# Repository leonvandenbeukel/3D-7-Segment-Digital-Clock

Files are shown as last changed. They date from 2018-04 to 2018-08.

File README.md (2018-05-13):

# 3D-7-Segment-Digital-Clock

This is the source and schema for another homemade digital clock I've made. Here's a link to the [YouTube video](https://youtu.be/QDYH36tWzoY)

Keep in mind that it takes a long time to print all the parts and in daylight it's not very bright.
You can download the Android app from the Play Story here: https://play.google.com/store/apps/details?id=nl.leonvandenbeukel.BTDigitalClockApp

### Print instructions

For better contrast, it's best to print the following parts in black:

* Betweenblock
* BewteenSegments
* DotRing
* Dotbottom
* Middle
* OuterRingSegments

The rest can be printed in white.

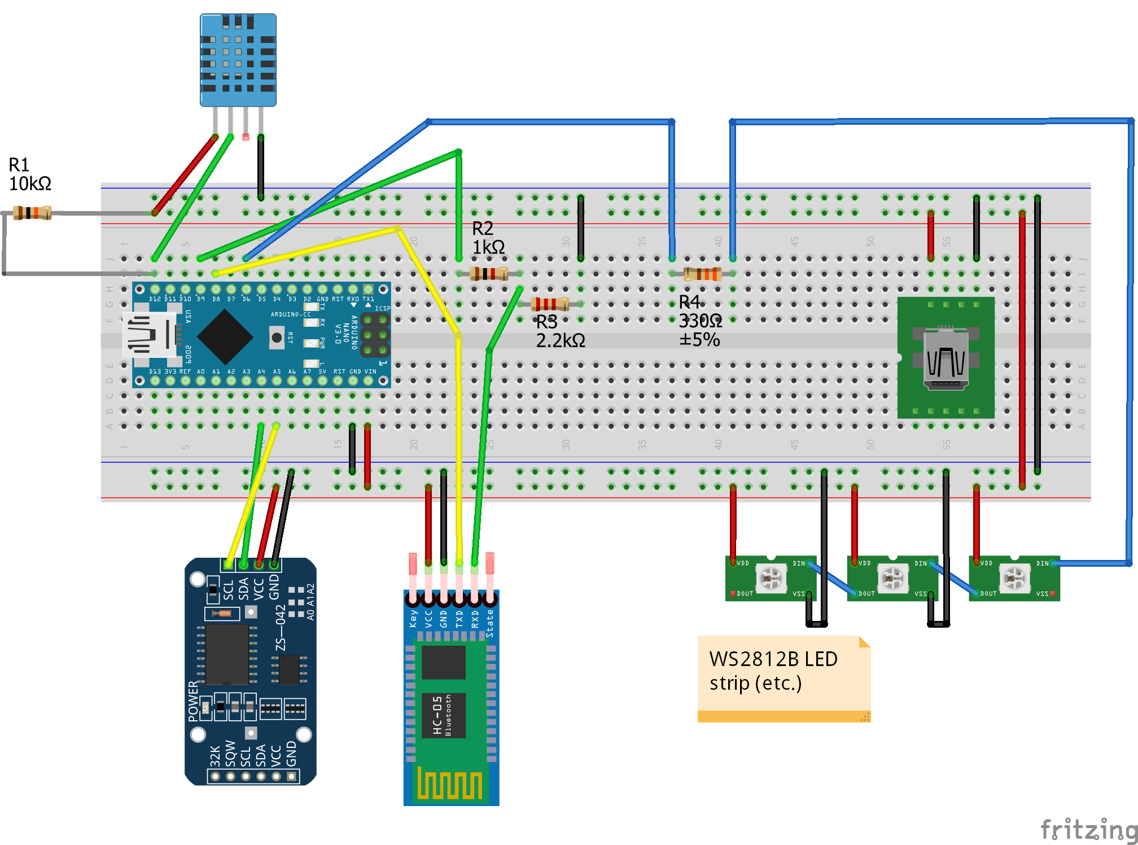
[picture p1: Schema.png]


| Components                              			    |
| -------------                          			      |
| Arduino Nano                           			      |
| LED strip WS2812B 1 meter 30 RGB LED's		 	      |
| Real time clock: DS3231 and battery          		  |
| Bluetooth module: HC-05                 			    |
| Temperature and Humidity Sensor: DHT11 or DHT22  	|
| 5V / 2A  Power Supply								              |
| PCB                                    			      |
| Wires, Glue and a lot of patience :)    			    |

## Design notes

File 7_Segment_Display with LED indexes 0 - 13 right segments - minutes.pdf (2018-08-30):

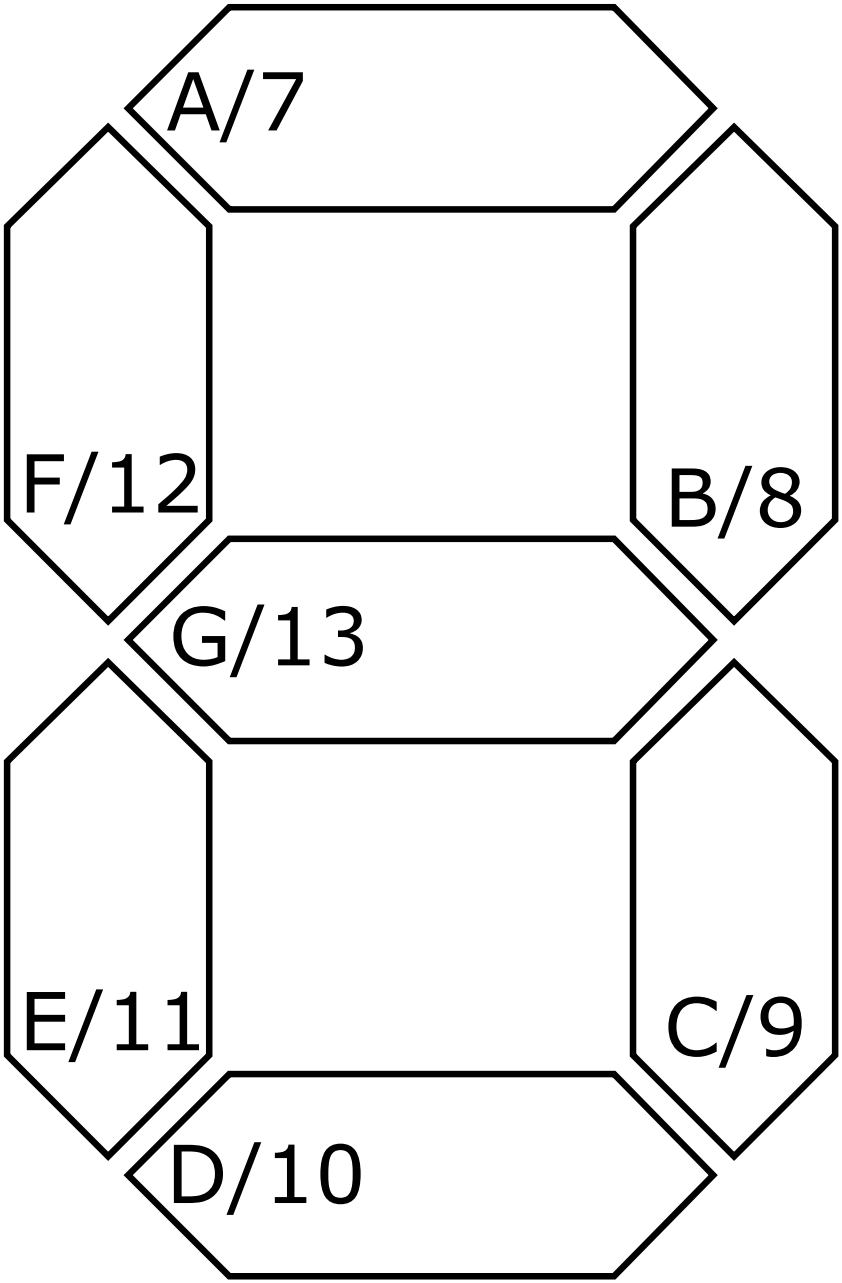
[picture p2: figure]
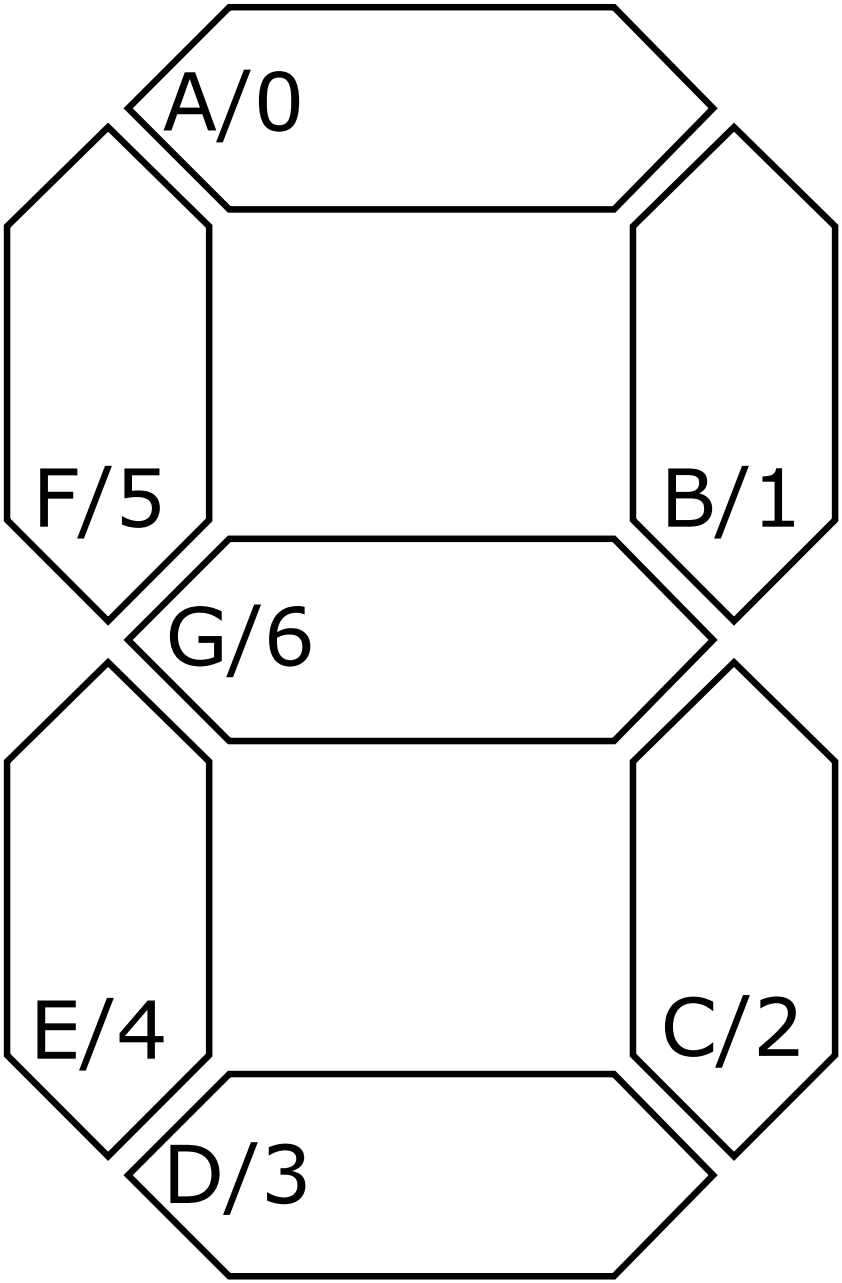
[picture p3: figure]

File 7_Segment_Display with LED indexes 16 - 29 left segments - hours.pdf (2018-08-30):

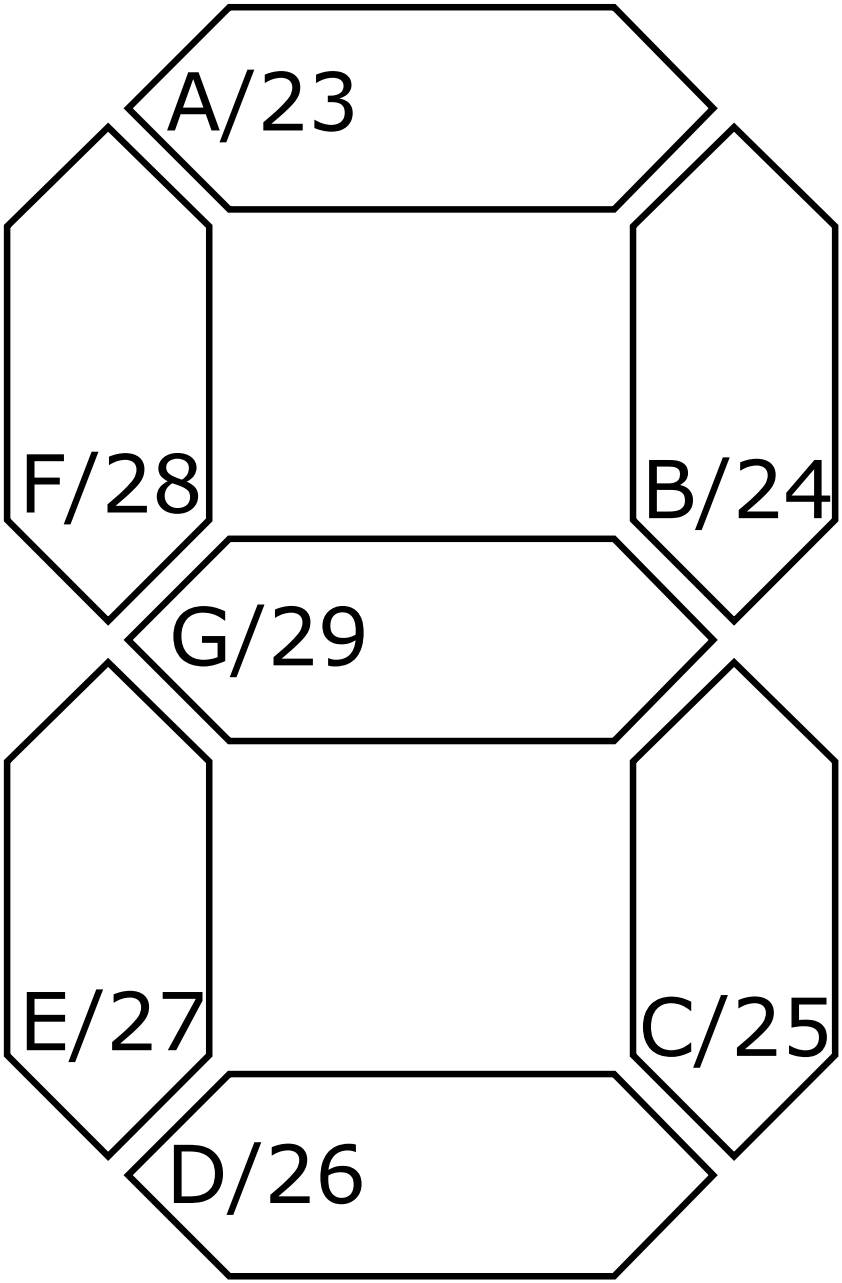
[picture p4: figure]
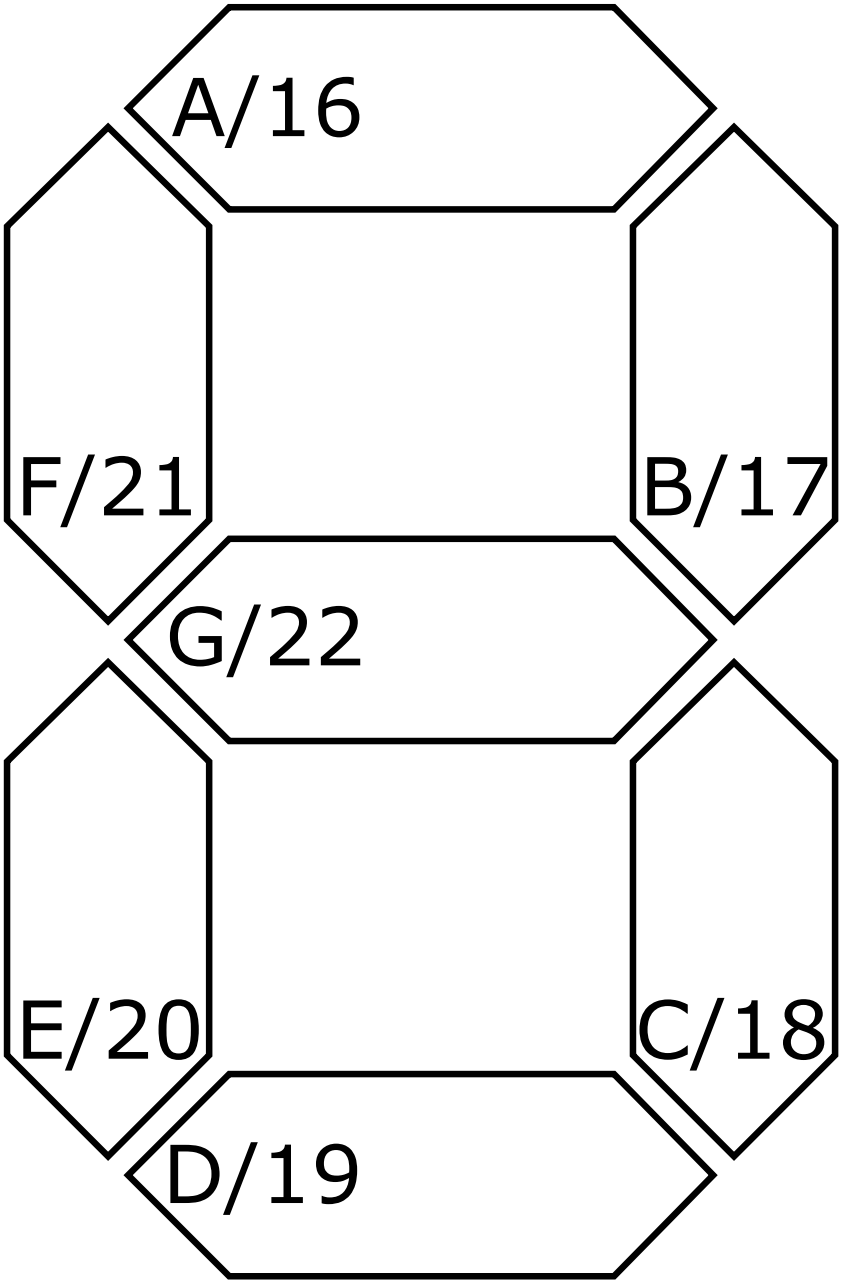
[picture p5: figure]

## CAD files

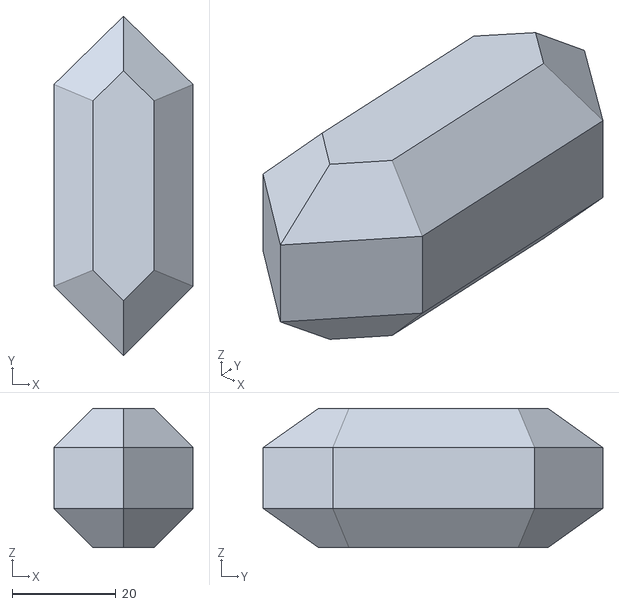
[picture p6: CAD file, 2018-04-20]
STL/Vertical Segment.stl
26.7 x 65.3 x 26.7

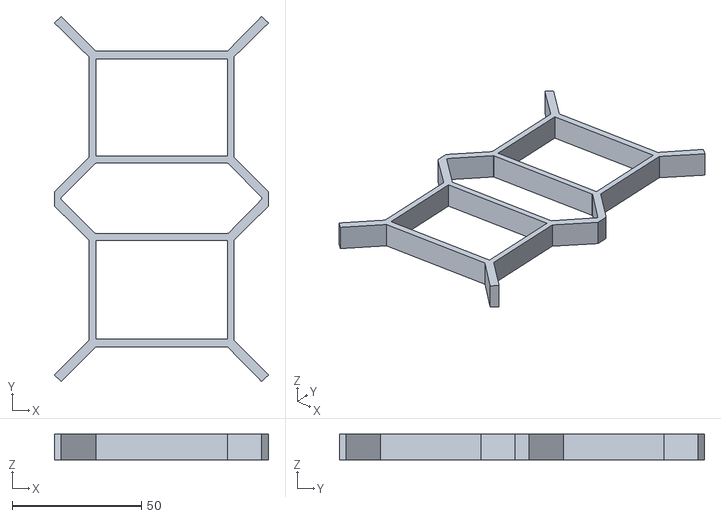
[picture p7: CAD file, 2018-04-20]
STL/BewteenSegments.stl
82.8 x 141.1 x 10.0

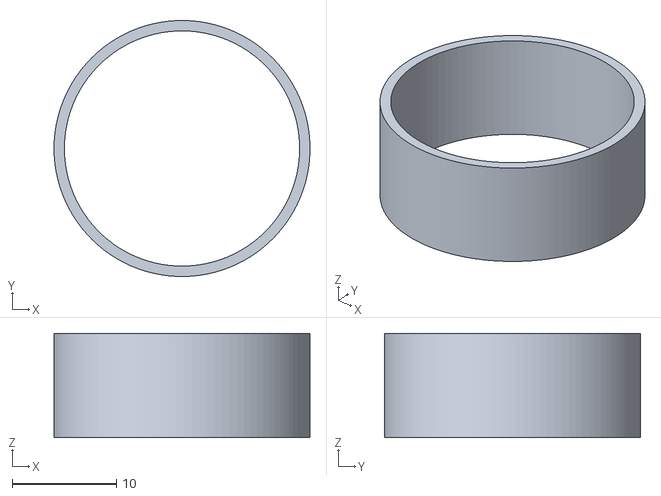
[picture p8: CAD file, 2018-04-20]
STL/DotRing.stl
24.6 x 24.6 x 10.0

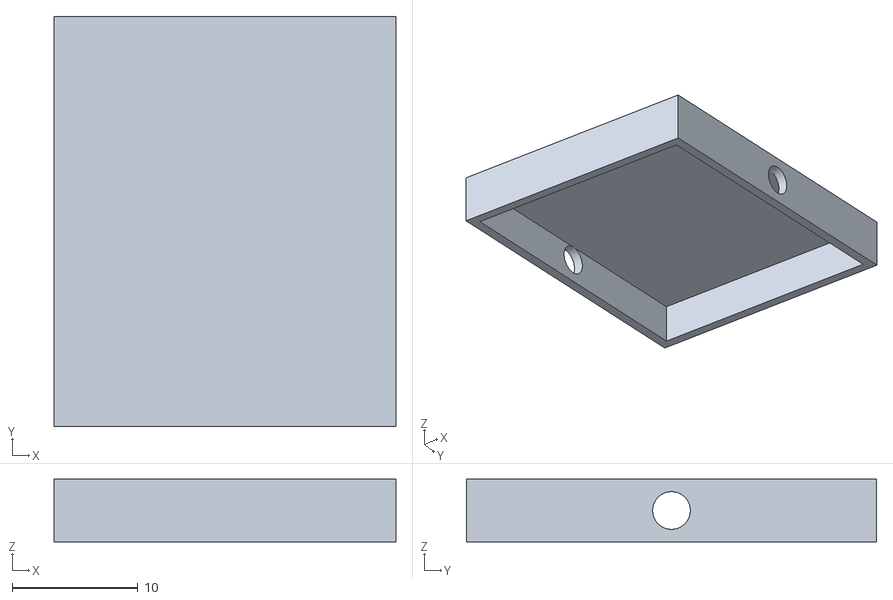
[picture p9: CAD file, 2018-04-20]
STL/Betweenblock.stl
27.2 x 32.6 x 5.00

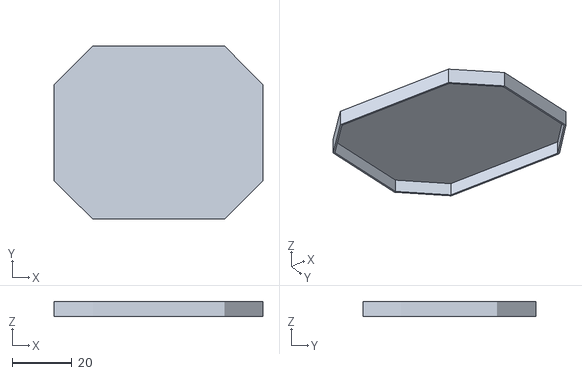
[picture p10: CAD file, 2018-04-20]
STL/Middle.stl
70.3 x 58.2 x 5.00

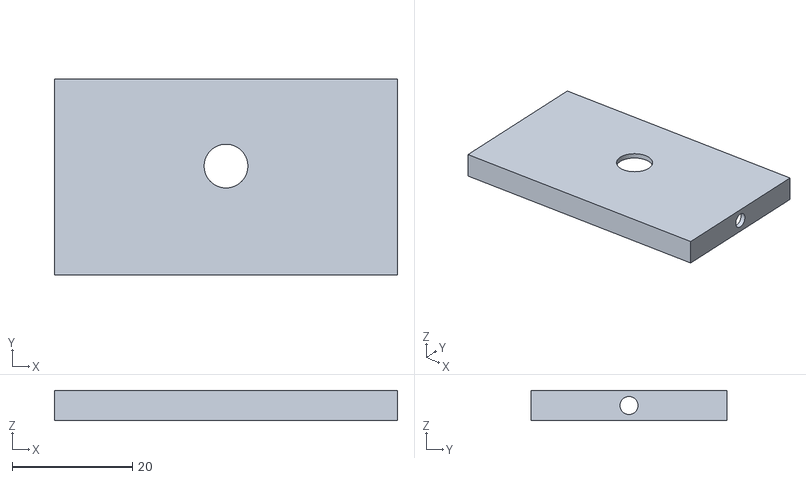
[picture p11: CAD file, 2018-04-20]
STL/Dotbottom.stl
57.0 x 32.6 x 5.00

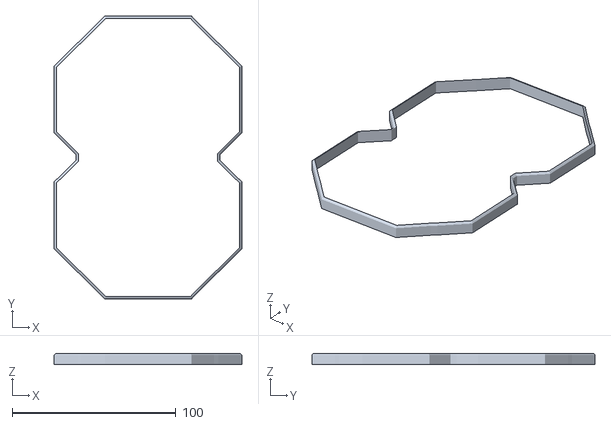
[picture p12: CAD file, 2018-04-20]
STL/OuterRingSegments.stl
114.5 x 172.8 x 7.00

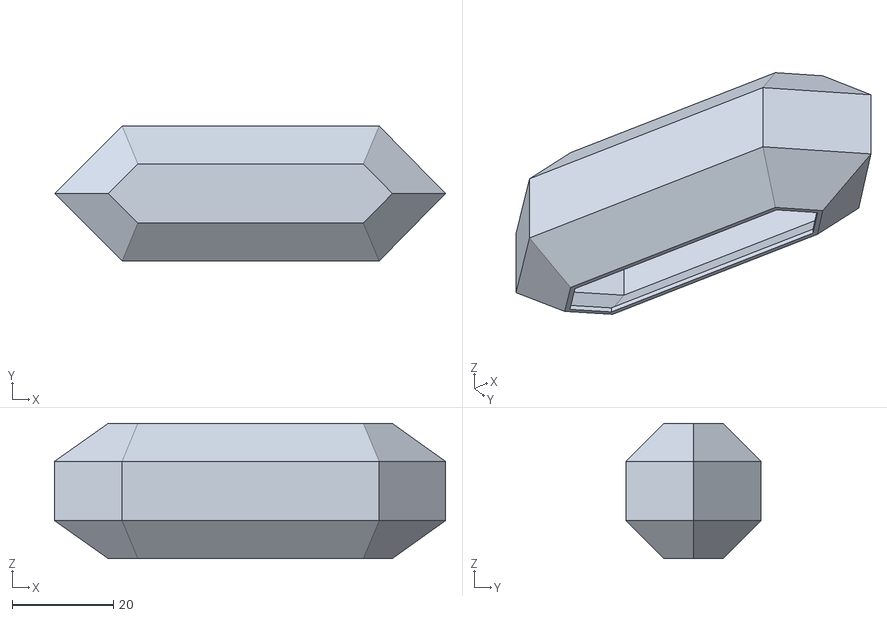
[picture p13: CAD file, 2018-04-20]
STL/Horizontal Segment.stl
77.4 x 26.7 x 26.7

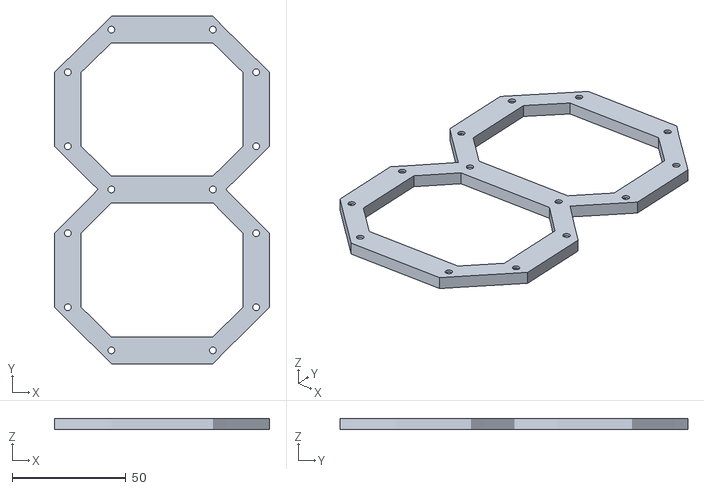
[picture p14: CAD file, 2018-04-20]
STL/Segmentbottom.stl
94.5 x 152.8 x 5.00

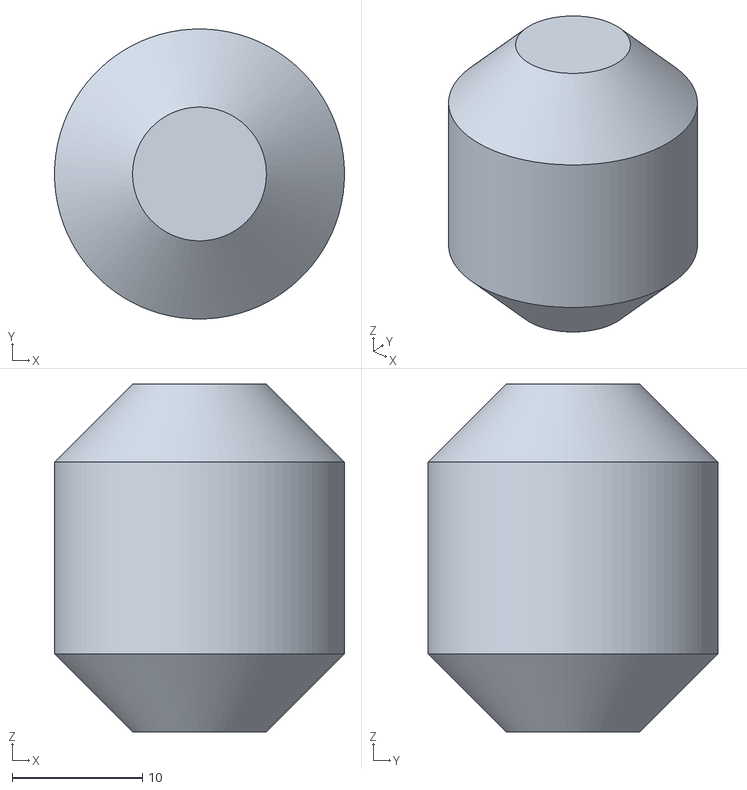
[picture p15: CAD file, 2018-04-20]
STL/Dot.stl
22.3 x 22.3 x 26.7

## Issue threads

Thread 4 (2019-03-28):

Release STL on Thingiverse

fleaz, 2019-03-28:
Hi,

first of all: Thanks for this nice project. Will start to print it myself as soon as I have restocked my PLA ^^

My suggestion would be to publish the STL files on Thingiverse. This way a lot more people would see this cool project and can also share pictures of their prints and start to remix the files or help each other in the comments section.

In my opinion this is a better platform for 3D Objects than GitHub.

Best regards,
Felix

leonvandenbeukel, 2019-05-04:
Hi, sorry for the late response. The STL files are also on thingiverse: https://www.thingiverse.com/thing:2871608

Closed 2019-05-04.

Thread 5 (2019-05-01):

Pease help to sketch

Billyflora, 2019-05-01:
hi, my name is fabio.
I desperately need your help.
unfortunately I have problems with your sketch and I'm not able to fix it ..
I can kindly and politely ask you if you send me a complete and finished sketch to put only on arduino and send it to billyflora@libero.it?
I did not want to bother you but I have everything ready for 6 months but I am still like a stone.
Thanks a lot, I still hope for your help.
Mondellini fabio

leonvandenbeukel, 2019-05-04:
Hi Fabio,

You can find a complete and finished sketch for Arduino here:

https://github.com/leonvandenbeukel/3D-7-Segment-Digital-Clock/blob/master/3D-7-Segment-Digital-Clock.ino

If you have any issues please be more specific with details of what is going wrong.

Regards,
Leon

Billyflora, 2019-05-04:
hi leon.
I thank you very much for your reply.
I managed to start it, but I would like to put two LEDs per segment instead of one ..
unfortunately I don't know how it gets ...
Would you be so kind as to change yours for my watch project?
I saw yours and I immediately fell in love with it, but with a LED you can't see anything.
I thank you so much again ..
I'm sorry for my goat disability!
I'm trying to learn slowly ...

Billyflora, 2019-05-05:
I'm sorry, another thing ...
I can not understand from the video the lap you did do you have led .. I do not understand the pattern of the turn of the LEDs on the printed numbers ..

Closed 2019-05-04.

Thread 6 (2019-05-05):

ciao sono fabio

Billyflora, 2019-05-05:
hi leon.
I thank you very much for your reply.
I managed to start it, but I would like to put two LEDs per segment instead of one ..
unfortunately I don't know how it gets ...
Would you be so kind as to change yours for my watch project?
I saw yours and I immediately fell in love with it, but with a LED you can't see anything.
I thank you so much again ..
I'm sorry for my goat disability!
I'm trying to learn slowly ...

I'm sorry, another thing ...
I can not understand from the video the lap you did do you have led .. I do not understand the pattern of the turn of the LEDs on the printed numbers ..

margaritpoutsi, 2019-11-11:
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

I would change this bit:
```
void displaySegments(int startindex, int number) {

  **byte** numbers[] = {
    0b00111111, // 0
    0b00000110, // 1
    0b01011011, // 2
    0b01001111, // 3
    0b01100110, // 4
    0b01101101, // 5
    0b01111101, // 6
    0b00000111, // 7
    0b01111111, // 8
    0b01101111, // 9
    0b01100011, // º              10
    0b00111001, // C(elcius)      11
    0b01011100, // º lower        12
    0b00000000, // Empty          13
    0b01110001, // F(ahrenheit)   14
  };

  for (int i = 0; i < **7**; i++) {
    LEDs[i + startindex] = ((numbers[number] & 1 << i) == 1 << i) ? (colorMODE == 0 ? colorCRGB : colorCHSV) : colorOFF;
  }
}
```

to this:
```
void displaySegments(int startindex, int number) {

  **int** numbers[] = {
    0b000111111111111, // 0
    0b000000000111100, // 1
    0b011001111001111, // 2
    0b011000011111111, // 3
    0b011110000111100, // 4
    0b011110011110011, // 5
    0b011111111110011, // 6
    0b000000000111111, // 7
    0b011111111111111, // 8
    0b011110011111111, // 9
    0b011110000001111, // º              10
    0b000111111000011, // C(elcius)      11
    0b011001111110000, // º lower        12
    0b000000000000000, // Empty          13
    0b011111100000011, // F(ahrenheit)   14
  };

  for (int i = 0; i < **14**; i++) {
    LEDs[i + startindex] = ((numbers[number] & 1 << i) == 1 << i) ? (colorMODE == 0 ? colorCRGB : colorCHSV) : colorOFF;
  }
}
```
and this:
  ```
  displaySegments(**0**, mr);
  displaySegments(**7**, ml);
  displaySegments(**16**, hr);
  displaySegments(**23**, hl);
```

to:
```
  displaySegments(**0**, mr);
  displaySegments(**14**, ml);
  displaySegments(**30**, hr);
  displaySegments(**44**, hl);
etc.
```

Dante6214, 2019-11-22:
Hi, the easiest way to make 2 LEDs per segment is to make a diagram so that there is a parallel connection of 2 LEDs as in the picture. And absolutely no need to change the sketch.
The picture is available at  link:
https://yadi.sk/i/FBnUcPGQ3qxf7w

pakobrien, 2021-04-17:
I do this but my dots don´t blink,the segment number 8 (leds 15 and 16)are always on and blinking,any solution?

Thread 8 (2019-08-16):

problem with LED

icepol001, 2019-08-16:
I made your clock but I have a problem with LEDs.
places that should not shine are glowing white. can you help me ? thank you

Milius605, 2019-08-17:
I have same problem. Pls help :-D

leonvandenbeukel, 2019-08-18:
Please check the .ino file on line 59:

CRGB colorOFF  = CRGB(20,20,20);      // Color of the segments that are 'disabled'. You can also set it to CRGB::Black

Change "CRGB(20,20,20)" to CRGB::Black if you don't want a glowing white.

Milius605, 2019-08-18:
It works! Thank you very much for your help and quick response

Closed 2019-08-19.

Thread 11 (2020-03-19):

Bluetooth

bilacom, 2020-03-19:
Hai Leon, I'm very interesting of your project and tried to make one, but I have problem with bluetooth connection.after I installed the aplication from playstore and trial it couldnt connect the bluetooth, aplication suddenly stop and close right after i click the BT device. FYI i use HC-06 instead of HC-05.

kikidu971-cpu, 2024-09-11:
Hi Leon,
I'm also interested in your clock. for the blutooth to work, I suppose i need the (digital clock app) installed on a smartphone. I haven't found the apk to install it. where can I find it? thanks.
chris

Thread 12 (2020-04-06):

HELP !! electric scheme

COIScois, 2020-04-06:
Thank you for this wonderful project.
As a CNC miller, the electrical part is a nice bump to take.
I follow the two schemes for the left and right digit groups.
I still follow the PCB board.
But do you also have a schedule where the 2 points are connected?

That is a mystery to me. That is certainly my ignorance!

thanks again for this great project.

dank je wel, François H

Closed 2020-04-06.

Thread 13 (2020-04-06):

Je hulp gevraagd !?

COIScois, 2020-04-06:
Thank you for this wonderful project.
As a CNC miller, the electrical part is a nice bump to take.
I follow the two schemes for the left and right digit groups.
I still follow the PCB board.
But do you also have a schedule where the 2 points are connected?

That is a mystery to me. That is certainly my ignorance!

thanks again for this great project.

dank je wel, François H

leonvandenbeukel, 2020-06-26:
They are connected in between the segments, just follow the LEDs from right to left.

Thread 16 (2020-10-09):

Resistor Conflict

DeimonGaming, 2020-10-09:
Im in the middle of creating this project. But ive been stuck on the R1, the resistor is placed at the same place as the humidity sensor can you please enlighten me

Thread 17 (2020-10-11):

Temp and Humidity not working

DeimonGaming, 2020-10-11:
I already finish this project, but im not submitting it yet the other functions like time, colors, scoreboard and timer are working but the temp and humidity is not ive already tried replacing wires and it still didnt work please help ASAP

madeinholland, 2021-05-08:
I have the same issue , Humidity and temp is not working

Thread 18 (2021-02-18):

'displayClock' was not declared in this scope

djgorandj, 2021-02-18:
Arduino say this:
'displayClock' was not declared in this scope
how to resolve this problem?

djgorandj, 2021-02-18:
Upload working, dont use beta 1.9 ardiono

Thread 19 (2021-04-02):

Lamps won't turn on

madeinholland, 2021-04-02:
I have gone to upload the firmware with the liberals tho the nano.
But when I am connected to de Bluetooth HC-05 and in the app, the lamp doesn't work.

my wiring is good it has voltage over eas lamp (+5v).  The only thing is it won't light up any of the lamps I think it lays in the android app. because I didn't make any changes in the liberals and your document.

the Din and ground do not have voltage over them. Besides that, the lamps can be turned on when I put voltage over them.
P.S I did not yet power it from the adaptor but with my pc.

Leon, can you help me tho finish your product?

Alex-Ender35, 2023-06-17:
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

Hello. Have you been able to solve the problem with the lamps not working? If so, how?

Closed 2021-05-08.

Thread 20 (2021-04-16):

problems with dots

pakobrien, 2021-04-16:
Hi Leon, first thank you very much for the project, I really liked it and I decided to do it.
The problem I have is that I have manufactured your watch but with two LEDs, I have read the posts and I have modified the .ino but now the points do not work and I have the A7 segment blinking as if they were the points, in the points I have only put a led in each one, I have a total of 58 leds, what should I change to fix this? The humidity temperature does not work either, thanks in advance

pakobrien, 2021-04-17:
resolved,I need to change this:

void displayDots(int dotMode) {
  // dotMode: 0=Both on, 1=Both Off, 2=Bottom On, 3=Blink
  switch (dotMode) {
    case 0:
      LEDs[28] = colorMODE == 0 ? colorCRGB : colorCHSV;
      LEDs[29] = colorMODE == 0 ? colorCRGB : colorCHSV;
      break;
    case 1:
      LEDs[28] = colorOFF;
      LEDs[29] = colorOFF;
      break;
    case 2:
      LEDs[28] = colorOFF;
      LEDs[29] = colorMODE == 0 ? colorCRGB : colorCHSV;
      break;
    case 3:
      LEDs[28] = (LEDs[28] == colorOFF) ? (colorMODE == 0 ? colorCRGB : colorCHSV) : colorOFF;
      LEDs[29] = (LEDs[29] == colorOFF) ? (colorMODE == 0 ? colorCRGB : colorCHSV) : colorOFF;
      FastLED.show();

Closed 2021-04-17.

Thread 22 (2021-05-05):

Problems compiling

m0nde, 2021-05-05:
I am no expert in Arduino and trying to build this clock for my son. I have built the hardware and he has printed all the clock pieces. When I compile the code for the nano I get this error.  Can someone please help me get past this issue please?
Arduino: 1.8.13 (Windows 10), Board: "Arduino Nano, ATmega328P"

In file included from C:\Users\nigel\Documents\Arduino\libraries\src/bitswap.h:4:0,

                 from C:\Users\nigel\Documents\Arduino\3D-7-Segment-Digital-Clock-master\3D-7-Segment-Digital-Clock-master\3D-7-Segment-Digital-Clock\3D-7-Segment-Digital-Clock.ino:1:

C:\Users\nigel\Documents\Arduino\libraries\src/FastLED.h:14:21: note: #pragma message: FastLED version 3.004.000

 #    pragma message "FastLED version 3.004.000"

                     ^~~~~~~~~~~~~~~~~~~~~~~~~~~

C:\Users\nigel\AppData\Local\Temp\ccKsavlE.ltrans0.ltrans.o: In function `displayClock':

C:\Users\nigel\Documents\Arduino\3D-7-Segment-Digital-Clock-master\3D-7-Segment-Digital-Clock-master\3D-7-Segment-Digital-Clock/3D-7-Segment-Digital-Clock.ino:267: undefined reference to `RTC_DS3231::now()'

C:\Users\nigel\AppData\Local\Temp\ccKsavlE.ltrans0.ltrans.o: In function `processCommand':

C:\Users\nigel\Documents\Arduino\3D-7-Segment-Digital-Clock-master\3D-7-Segment-Digital-Clock-master\3D-7-Segment-Digital-Clock/3D-7-Segment-Digital-Clock.ino:240: undefined reference to `DateTime::DateTime(unsigned int, unsigned char, unsigned char, unsigned char, unsigned char, unsigned char)'

C:\Users\nigel\Documents\Arduino\3D-7-Segment-Digital-Clock-master\3D-7-Segment-Digital-Clock-master\3D-7-Segment-Digital-Clock/3D-7-Segment-Digital-Clock.ino:240: undefined reference to `RTC_DS3231::adjust(DateTime const&)'

C:\Users\nigel\AppData\Local\Temp\ccKsavlE.ltrans0.ltrans.o: In function `global constructors keyed to 65535_0_3D_7_Segment_Digital_Clock.ino.cpp.o.4410':

<artificial>:(.text.startup+0x1bc): undefined reference to `Timer::Timer()'

<artificial>:(.text.startup+0x1c4): undefined reference to `Timer::Timer()'

<artificial>:(.text.startup+0x1cc): undefined reference to `Timer::Timer()'

C:\Users\nigel\AppData\Local\Temp\ccKsavlE.ltrans0.ltrans.o: In function `setup':

C:\Users\nigel\Documents\Arduino\3D-7-Segment-Digital-Clock-master\3D-7-Segment-Digital-Clock-master\3D-7-Segment-Digital-Clock/3D-7-Segment-Digital-Clock.ino:118: undefined reference to `RTC_DS3231::begin()'

C:\Users\nigel\Documents\Arduino\3D-7-Segment-Digital-Clock-master\3D-7-Segment-Digital-Clock-master\3D-7-Segment-Digital-Clock/3D-7-Segment-Digital-Clock.ino:123: undefined reference to `RTC_DS3231::lostPower()'

C:\Users\nigel\Documents\Arduino\3D-7-Segment-Digital-Clock-master\3D-7-Segment-Digital-Clock-master\3D-7-Segment-Digital-Clock/3D-7-Segment-Digital-Clock.ino:126: undefined reference to `DateTime::DateTime(__FlashStringHelper const*, __FlashStringHelper const*)'

C:\Users\nigel\Documents\Arduino\3D-7-Segment-Digital-Clock-master\3D-7-Segment-Digital-Clock-master\3D-7-Segment-Digital-Clock/3D-7-Segment-Digital-Clock.ino:126: undefined reference to `RTC_DS3231::adjust(DateTime const&)'

C:\Users\nigel\Documents\Arduino\3D-7-Segment-Digital-Clock-master\3D-7-Segment-Digital-Clock-master\3D-7-Segment-Digital-Clock/3D-7-Segment-Digital-Clock.ino:129: undefined reference to `Timer::every(unsigned long, void (*)())'

C:\Users\nigel\Documents\Arduino\3D-7-Segment-Digital-Clock-master\3D-7-Segment-Digital-Clock-master\3D-7-Segment-Digital-Clock/3D-7-Segment-Digital-Clock.ino:130: undefined reference to `Timer::every(unsigned long, void (*)())'

C:\Users\nigel\Documents\Arduino\3D-7-Segment-Digital-Clock-master\3D-7-Segment-Digital-Clock-master\3D-7-Segment-Digital-Clock/3D-7-Segment-Digital-Clock.ino:131: undefined reference to `Timer::every(unsigned long, void (*)())'

C:\Users\nigel\AppData\Local\Temp\ccKsavlE.ltrans0.ltrans.o: In function `loop':

C:\Users\nigel\Documents\Arduino\3D-7-Segment-Digital-Clock-master\3D-7-Segment-Digital-Clock-master\3D-7-Segment-Digital-Clock/3D-7-Segment-Digital-Clock.ino:137: undefined reference to `Timer::update()'

C:\Users\nigel\Documents\Arduino\3D-7-Segment-Digital-Clock-master\3D-7-Segment-Digital-Clock-master\3D-7-Segment-Digital-Clock/3D-7-Segment-Digital-Clock.ino:138: undefined reference to `Timer::update()'

C:\Users\nigel\Documents\Arduino\3D-7-Segment-Digital-Clock-master\3D-7-Segment-Digital-Clock-master\3D-7-Segment-Digital-Clock/3D-7-Segment-Digital-Clock.ino:139: undefined reference to `Timer::update()'

collect2.exe: error: ld returned 1 exit status

exit status 1

Error compiling for board Arduino Nano.

This report would have more information with
"Show verbose output during compilation"
option enabled in File -> Preferences.

Alex-Ender35, 2023-06-15:
Hello, m0nde, you managed to solve your problem with the compilation errors. If so, how?

Alex-Ender35, 2023-06-15:
Какие библиотеки вы использовали? Или может быть внесли изменения в коде прошивки?

m0nde, 2023-06-15:
Sorry no luck here

kind regards

Nigel

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

Alex-Ender35, 2023-06-15:
> Извините, здесь не повезло, с уважением, Найджел.
> […](#)
> Чт, 15 Июн 2023, 02:36 Alex-Ender35, ***@***.***> написал: Здравствуйте, m0nde, вам удалось решить проблему с ошибками компиляции. Если да, то как? — Ответьте на это письмо напрямую, просмотрите его на GitHub < [# 22 (комментарий)](https://github.com/leonvandenbeukel/3D-7-Segment-Digital-Clock/issues/22#issuecomment-1592201153) > или отмените подписку < https://github.com/notifications/unsubscribe-auth/ACJHOW2OUBRURH4WYW3SLXDXLJRJDANCNFSM44FM7I6A > . Вы получили это сообщение, потому что являетесь автором темы. Идентификатор сообщения: ***@***.*** com>

Genasaf, 2024-05-09:
Все работает скетч грузится

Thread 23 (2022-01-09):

error

JBHTv, 2022-01-09:
Sketch uses 18084 bytes (58%) of program storage space. Maximum is 30720 bytes.
Global variables use 1491 bytes (72%) of dynamic memory, leaving 557 bytes for local variables. Maximum is 2048 bytes.
avrdude: stk500_recv(): programmer is not responding
avrdude: stk500_getsync() attempt 1 of 10: not in sync: resp=0x04
avrdude: stk500_recv(): programmer is not responding
avrdude: stk500_getsync() attempt 2 of 10: not in sync: resp=0x04
avrdude: stk500_recv(): programmer is not responding
avrdude: stk500_getsync() attempt 3 of 10: not in sync: resp=0x04
avrdude: stk500_recv(): programmer is not responding
avrdude: stk500_getsync() attempt 4 of 10: not in sync: resp=0x04
avrdude: stk500_recv(): programmer is not responding
avrdude: stk500_getsync() attempt 5 of 10: not in sync: resp=0x04
avrdude: stk500_recv(): programmer is not responding
avrdude: stk500_getsync() attempt 6 of 10: not in sync: resp=0x04
avrdude: stk500_recv(): programmer is not responding
avrdude: stk500_getsync() attempt 7 of 10: not in sync: resp=0x04
avrdude: stk500_recv(): programmer is not responding
avrdude: stk500_getsync() attempt 8 of 10: not in sync: resp=0x04
avrdude: stk500_recv(): programmer is not responding
avrdude: stk500_getsync() attempt 9 of 10: not in sync: resp=0x04
avrdude: stk500_recv(): programmer is not responding
avrdude: stk500_getsync() attempt 10 of 10: not in sync: resp=0x04
Problem uploading to board.  See https://support.arduino.cc/hc/en-us/sections/360003198300 for suggestions.

JBHTv, 2022-01-09:
only change processor to ATmega328p (Old Bootloader)

Closed 2022-01-09.

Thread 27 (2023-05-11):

Arduino software

lorcott, 2023-05-11:
I'm using an ESP32 and I cannot find the code to run the clock. Any help greatly appreciated.

slevine@lorcott.com
s

aeonSolutions, 2023-06-17:
I can do that for you. Send me a message to WhatsApp +32 471 632 520

Genasaf, 2024-04-14:
help with the application it is not on google play

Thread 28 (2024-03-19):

Google play missing app

tamgor, 2024-03-19:
I changed my phone, unfortunately there is no more app on google play.

Im asking for help

ZioRaff, 2024-04-06:
I have the same problem but can't I get the app code?

Genasaf, 2024-04-14:
Поделитесь файлом загрузки приложения приложения

pjaspinski, 2024-07-03:
I made a Python script that can connect to the clock and set current time. You can find it here: https://github.com/pjaspinski/digital-clock-toolkit

Another way of communicating with the clock is to get an app that can send serial Bluetooth 2 messages. I successfully used this app: https://play.google.com/store/apps/details?id=de.kai_morich.serial_bluetooth_terminal
If you look into `processMessage` function in clock's code, you can deduct format of messages. For example, message used to set time has following format: `|RTC,2024,07,03,19,55,06`.

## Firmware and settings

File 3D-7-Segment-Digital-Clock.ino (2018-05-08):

/*
 * MIT License
 * 
 * Copyright (c) 2018 Leon van den Beukel
 * 
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
 * Source: 
 * https://github.com/leonvandenbeukel/3D-7-Segment-Digital-Clock
 * 
 * External libraries you need:
 * Adafruit Sensor Library:   https://github.com/adafruit/Adafruit_Sensor
 * Adafruit RTCLib:           https://github.com/adafruit/RTClib
 * FastLED:                   https://github.com/FastLED/FastLED
 * Timer Library:             https://github.com/JChristensen/Timer
 */

#include <DHT.h>
#include <DHT_U.h>
#include <FastLED.h>
#include <Wire.h>
#include "RTClib.h"
#include <SoftwareSerial.h>
#include "Timer.h"

#define DHTPIN 12
#define DHTTYPE DHT11
DHT dht(DHTPIN, DHTTYPE);

#define NUM_LEDS 30     
#define DATA_PIN 6
CRGB LEDs[NUM_LEDS];

SoftwareSerial BTserial(8, 9);
RTC_DS3231 rtc;
Timer t1;
Timer t2;
Timer t3;

String btBuffer;
CRGB colorCRGB = CRGB::Red;           // Change this if you want another default color, for example CRGB::Blue
CHSV colorCHSV = CHSV(95, 255, 255);  // Green
CRGB colorOFF  = CRGB(20,20,20);      // Color of the segments that are 'disabled'. You can also set it to CRGB::Black
volatile int colorMODE = 1;           // 0=CRGB, 1=CHSV, 2=Constant Color Changing pattern
volatile int mode = 0;                // 0=Clock, 1=Temperature, 2=Humidity, 3=Scoreboard, 4=Time counter
volatile int scoreLeft = 0;
volatile int scoreRight = 0;
volatile long timerValue = 0;
volatile int timerRunning = 0;

#define blinkDots   0                 // Set this to 1 if you want the dots to blink in clock mode, set it to value 0 to disable
#define hourFormat  24                // Set this to 12 or to 24 hour format
#define temperatureMode 'C'           // Set this to 'C' for Celcius or 'F' for Fahrenheit

void setup () {

  // Initialize LED strip
  FastLED.delay(3000);

  // Check if you're LED strip is a RGB or GRB version (third parameter)
  FastLED.addLeds<WS2812B, DATA_PIN, GRB>(LEDs, NUM_LEDS);

  Serial.begin(9600);
  while (!Serial) { /* Wait until serial is ready */ }

  BTserial.begin(9600);
  Serial.println("BTserial started at 9600");

  dht.begin();

  if (!rtc.begin()) {
    Serial.println("Couldn't find RTC");
    while (1);
  }

  if (rtc.lostPower()) {
    Serial.println("RTC lost power, lets set the time!");
    // following line sets the RTC to the date & time this sketch was compiled
    rtc.adjust(DateTime(F(__DATE__), F(__TIME__)));
  }
    
  t1.every(1000 * 29, refreshDisplay); 
  t2.every(1000, refreshTimer);
  t3.every(50, updateHue);
  refreshDisplay();
}

void loop () {
  
  t1.update(); 
  t2.update();
  t3.update();

  if (BTserial.available())
  {
    char received = BTserial.read();
    btBuffer += received; 

    if (received == '|')
    {
        processCommand();
        btBuffer = "";
    }
  }
}

void updateHue() {
  if (colorMODE != 2)
    return;
    
  colorCHSV.sat = 255;
  colorCHSV.val = 255;
  if (colorCHSV.hue >= 255){
    colorCHSV.hue = 0;
  } else {
    colorCHSV.hue++;
  }
  refreshDisplay();
}

void refreshDisplay() {
  switch (mode) {
    case 0:
      displayClock();
      break;
    case 1:
      displayTemperature();
      break;
    case 2:
      displayHumidity();
      break;
    case 3:
      displayScoreboard();
      break;      
    case 4:
      // Time counter has it's own timer
      break;
    default:   
      break; 
  }
}

void refreshTimer() {

  if (mode == 0 && blinkDots == 1) {    
    displayDots(3);
  } else if (mode == 4 && timerRunning == 1 && timerValue < 6000) {
    timerValue++;

    int m1 = (timerValue / 60) / 10 ;
    int m2 = (timerValue / 60) % 10 ;
    int s1 = (timerValue % 60) / 10;
    int s2 = (timerValue % 60) % 10;
  
    displaySegments(0, s2); 
    displaySegments(7, s1);
    displaySegments(16, m2);    
    displaySegments(23, m1);  
    displayDots(0);  
    FastLED.show();
  }
}

void processCommand(){

  if (btBuffer.startsWith("RGBD")) {
    long R = getValue(btBuffer, ',', 1).toInt();
    long G = getValue(btBuffer, ',', 2).toInt();
    long B = getValue(btBuffer, ',', 3).toInt();
    long D = getValue(btBuffer, ',', 4).toInt();
    colorCRGB.red = R;
    colorCRGB.green = G;
    colorCRGB.blue = B;
    colorMODE = 0;
    if (D > 0) FastLED.setBrightness(D); 
  } else if (btBuffer.startsWith("HSVD")) {
    long H = getValue(btBuffer, ',', 1).toInt();
    long S = getValue(btBuffer, ',', 2).toInt();
    long V = getValue(btBuffer, ',', 3).toInt();
    long D = getValue(btBuffer, ',', 4).toInt();
    colorCHSV.hue = H;
    colorCHSV.sat = S;
    colorCHSV.val = V;
    colorMODE = 1;
    if (D > 0) FastLED.setBrightness(D);
  } else if (btBuffer.startsWith("RTC")) {
    long y = getValue(btBuffer, ',', 1).toInt();
    long m = getValue(btBuffer, ',', 2).toInt();
    long d = getValue(btBuffer, ',', 3).toInt();
    long h = getValue(btBuffer, ',', 4).toInt();
    long mm = getValue(btBuffer, ',', 5).toInt();
    long s = getValue(btBuffer, ',', 6).toInt();
    rtc.adjust(DateTime(y, m, d, h, mm, s));
    Serial.println("DateTime set");
  } else if (btBuffer.startsWith("CLOCK")) {
    mode = 0;    
  } else if (btBuffer.startsWith("TEMPERATURE")) {
    mode = 1;    
  } else if (btBuffer.startsWith("HUMIDITY")) {
    mode = 2;
  } else if (btBuffer.startsWith("SCOREBOARD")) {
    scoreLeft = getValue(btBuffer, ',', 1).toInt();
    scoreRight = getValue(btBuffer, ',', 2).toInt();
    mode = 3;    
  } else if (btBuffer.startsWith("STARTTIMER")) {
    timerValue = 0;
    timerRunning = 1;
    mode = 4;    
  } else if (btBuffer.startsWith("STOPTIMER")) {
    timerRunning = 0;
    mode = 4;    
  } else if (btBuffer.startsWith("CHANGINGPATTERN")) {
    colorMODE = 2;
  }
  
  refreshDisplay();
}

void displayClock() {   
  DateTime now = rtc.now();

  int h  = now.hour();
  if (hourFormat == 12 && h > 12)
    h = h - 12;
  
  int hl = (h / 10) == 0 ? 13 : (h / 10);
  int hr = h % 10;
  int ml = now.minute() / 10;
  int mr = now.minute() % 10;

  displaySegments(0, mr);    
  displaySegments(7, ml);
  displaySegments(16, hr);    
  displaySegments(23, hl);  
  displayDots(0);  
  FastLED.show();
}

void displayTemperature() {
  float tmp = dht.readTemperature(temperatureMode == 'F' ? true : false);

  if (isnan(tmp)) {
    Serial.println("Failed to read from DHT sensor!");
  } else {
    int tmp1 = tmp / 10;
    int tmp2 = ((int)tmp) % 10;
    displaySegments(23, tmp1);    
    displaySegments(16, tmp2);
    displaySegments(7,  10);    
    displaySegments(0, (temperatureMode == 'F' ? 14 : 11));
    displayDots(1);  
    FastLED.show();    
  }  
}

void displayHumidity() {
  float hum = dht.readHumidity();

  if (isnan(hum)) {
    Serial.println("Failed to read from DHT sensor!");
  } else {
    int hum1 = hum / 10;
    int hum2 = ((int)hum) % 10;
    displaySegments(23, hum1);    
    displaySegments(16, hum2);
    displaySegments(7,  10);    
    displaySegments(0,  12);
    displayDots(1);  
    FastLED.show();    
  }  
}

void displayScoreboard() {
  int s1 = scoreLeft % 10;
  int s2 = scoreLeft / 10;
  int s3 = scoreRight % 10;
  int s4 = scoreRight / 10;
  displaySegments(0, s3);    
  displaySegments(7, s4);
  displaySegments(16, s1);    
  displaySegments(23, s2);
  displayDots(2);  
  FastLED.show();  
}

void displayDots(int dotMode) {
  // dotMode: 0=Both on, 1=Both Off, 2=Bottom On, 3=Blink
  switch (dotMode) {
    case 0:
      LEDs[14] = colorMODE == 0 ? colorCRGB : colorCHSV;
      LEDs[15] = colorMODE == 0 ? colorCRGB : colorCHSV; 
      break;
    case 1:
      LEDs[14] = colorOFF;
      LEDs[15] = colorOFF; 
      break;
    case 2:
      LEDs[14] = colorOFF;
      LEDs[15] = colorMODE == 0 ? colorCRGB : colorCHSV; 
      break;
    case 3:
      LEDs[14] = (LEDs[14] == colorOFF) ? (colorMODE == 0 ? colorCRGB : colorCHSV) : colorOFF;
      LEDs[15] = (LEDs[15] == colorOFF) ? (colorMODE == 0 ? colorCRGB : colorCHSV) : colorOFF;
      FastLED.show();  
      break;
    default:
      break;    
  }
}

void displaySegments(int startindex, int number) {

  byte numbers[] = {
    0b00111111, // 0    
    0b00000110, // 1
    0b01011011, // 2
    0b01001111, // 3
    0b01100110, // 4
    0b01101101, // 5
    0b01111101, // 6
    0b00000111, // 7
    0b01111111, // 8
    0b01101111, // 9   
    0b01100011, // º              10
    0b00111001, // C(elcius)      11
    0b01011100, // º lower        12
    0b00000000, // Empty          13
    0b01110001, // F(ahrenheit)   14
  };

  for (int i = 0; i < 7; i++) {
    LEDs[i + startindex] = ((numbers[number] & 1 << i) == 1 << i) ? (colorMODE == 0 ? colorCRGB : colorCHSV) : colorOFF;
  } 
}

String getValue(String data, char separator, int index) {
  int found = 0;
  int strIndex[] = {0, -1};
  int maxIndex = data.length()-1;

  for(int i=0; i<=maxIndex && found<=index; i++){
    if(data.charAt(i)==separator || i==maxIndex){
        found++;
        strIndex[0] = strIndex[1]+1;
        strIndex[1] = (i == maxIndex) ? i+1 : i;
    }
  }

  return found>index ? data.substring(strIndex[0], strIndex[1]) : "";
}

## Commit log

2018-04-21 Changed the name for Arduino IDE
    Changed the name so it's easier to use with the Arduino IDE (the name of the folder must be the same as the file name).
2018-04-21 Fixed leading zero when hour < 10
    [3D-7-Segment-Digital-Clock.ino]
2018-05-05 Update README.md
    Added print instructions
2018-05-08 Added option to set 12 or 24 hour mode and Celcius or Fahrenheit temperature mode
2018-05-08 Commented out some Serial.println for faster response
2018-05-08 Removed some Serial.print lines for faster response
2018-05-13 Added BOM after comment from viewer on YouTube
2018-08-30 Added files for the order of LED's
